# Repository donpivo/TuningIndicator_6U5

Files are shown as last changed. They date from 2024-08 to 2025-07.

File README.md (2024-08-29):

# TuningIndicator_6U5
Project description: https://retronics.no/2024/08/29/diy-digital-6u5-magic-eye-replacement/
All PCB design files (KiCAD), fabrication files (gerber), 3D models (.stl) and code (C++, PlatformIO) are shared for personal use only; not for commercial use / sale of neither the complete solution nor parts of it.

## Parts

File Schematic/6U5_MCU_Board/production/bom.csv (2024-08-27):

Designator | Footprint | Quantity | Value | LCSC Part #
C1, C10, C3, C8, C9 | 0603 | 5 | 100nF
C2, C4, C5 | 0603 | 3 | 10µF
C6, C7 | 0603 | 2 | 20pF
FB1 | 0603 | 1 | 1kΩ@100MHz 500mΩ@DC
J1 | PinHeader_1x03_P2.54mm_Horizontal_Alt | 1 | Pin header
J2 | EMI_Shield_MS207-10S | 1 | EMI Shield
J3 | 0527450897 | 1 | FFC8
J4 | 505110-1292 | 1 | Display interface
Q1 | SOT-23 | 1 | BC847C
R1, R4 | 0603 | 2 | 10kΩ
R2 | 0603 | 1 | 2.2MΩ
R3 | 0603 | 1 | 15MΩ
R5 | 0603 | 1 | 1MΩ
R6 | 0603 | 1 | 10Ω
R7 | 0603 | 1 | 1kΩ
U1 | SOT-23-5 | 1 | MCP6001T-I/OT
U2 | LQFP-48_7x7mm_P0.5mm | 1 | STM32F103CBTx
U3 | SOT-223-3_TabPin2 | 1 | NCP1117-3.3_SOT223
Y1 | Crystal_SMD_3225-4Pin_3.2x2.5mm | 1 | XC32M4-8.000 12pF

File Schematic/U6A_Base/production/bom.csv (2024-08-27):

Designator | Footprint | Quantity | Value | LCSC Part #
C1 | CP_Radial_D8.0mm_P3.50mm_H21mm | 1 | 1000µF 16V
D1, D2 | D_SOD-323_HandSoldering | 2 | 1N5819WS
F1 | 1206 | 1 | T1A
FB1 | 0805 | 1 | 330Ω@100MHz
J1 | U6A_Base | 1 | U6A Base
J2 | PinSocket_1x03_P2.54mm_Vertical | 1 | Pin header

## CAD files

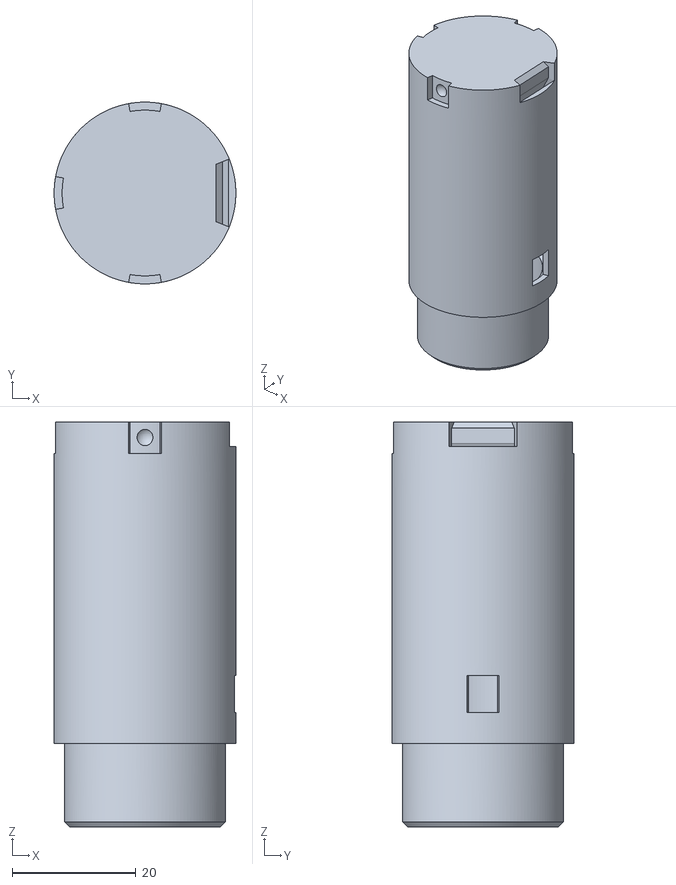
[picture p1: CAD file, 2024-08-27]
Models/6U5_Tube.stl
29.4 x 29.4 x 65.5

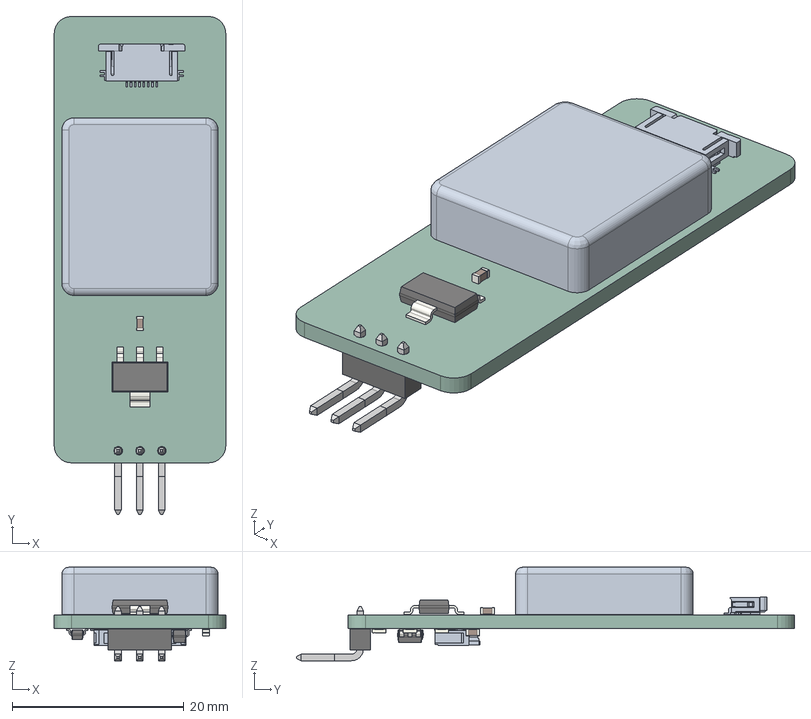
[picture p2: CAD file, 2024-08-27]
Schematic/6U5_MCU_Board/6U5_MCU_Board.step
20.0 x 58.0 x 10.9 mm
MS207-10S
SOT_223
C_0603_1608Metric x 3
R_0603_1608Metric x 3
SOT_23
SOT_23_5
PinHeader_022052031 v4
U6A_MCU_Board_PCB

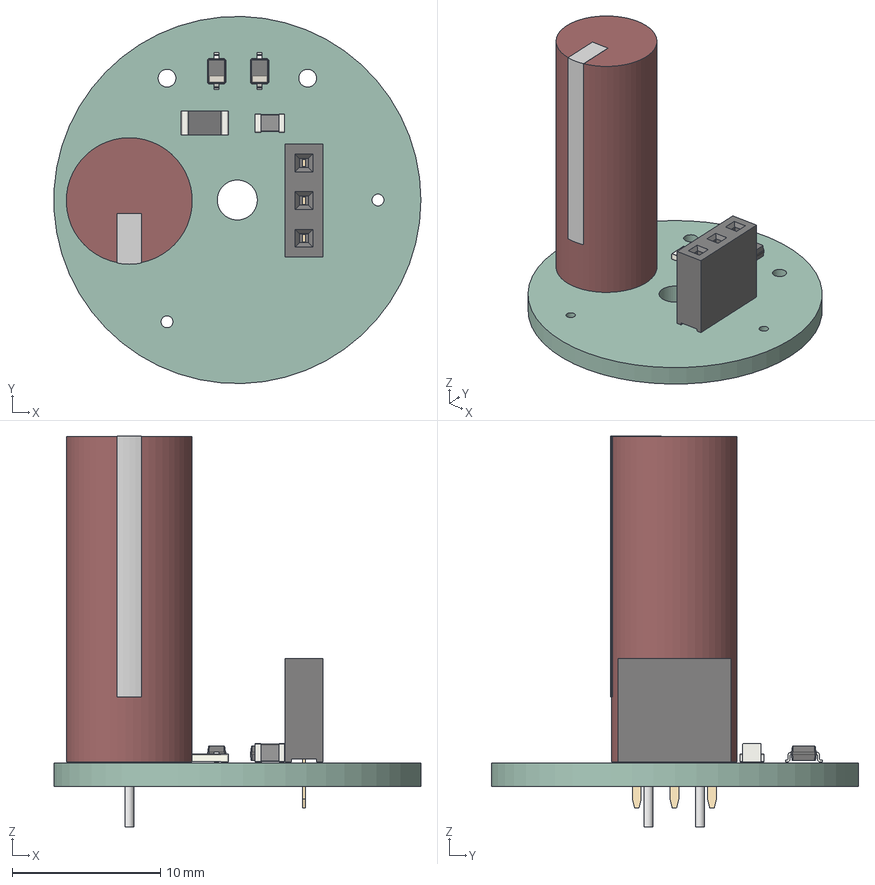
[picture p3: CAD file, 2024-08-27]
Schematic/U6A_Base/U6A_Base.step
24.8 x 24.8 x 26.4 mm
D_SOD_323 x 2
Fuse_1206_3216Metric
L_0805_2012Metric
PinSocket_1x03_P254mm_Vertical
U6A_Base_PCB

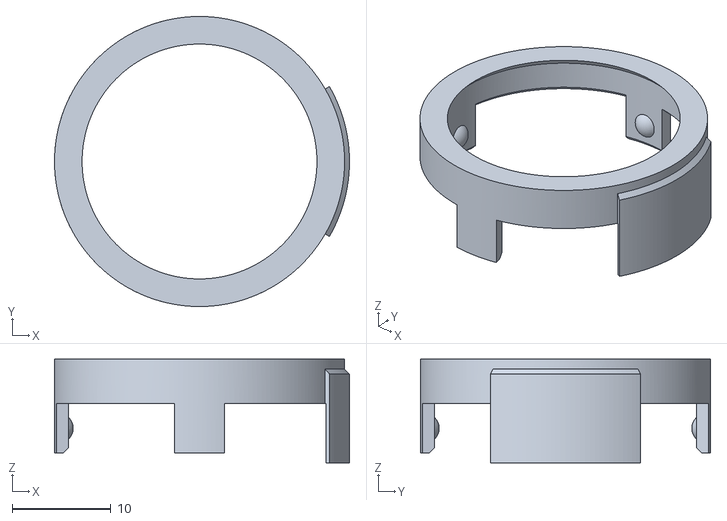
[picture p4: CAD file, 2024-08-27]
Models/6U5_DisplayBracket.stl
29.9 x 29.4 x 10.5

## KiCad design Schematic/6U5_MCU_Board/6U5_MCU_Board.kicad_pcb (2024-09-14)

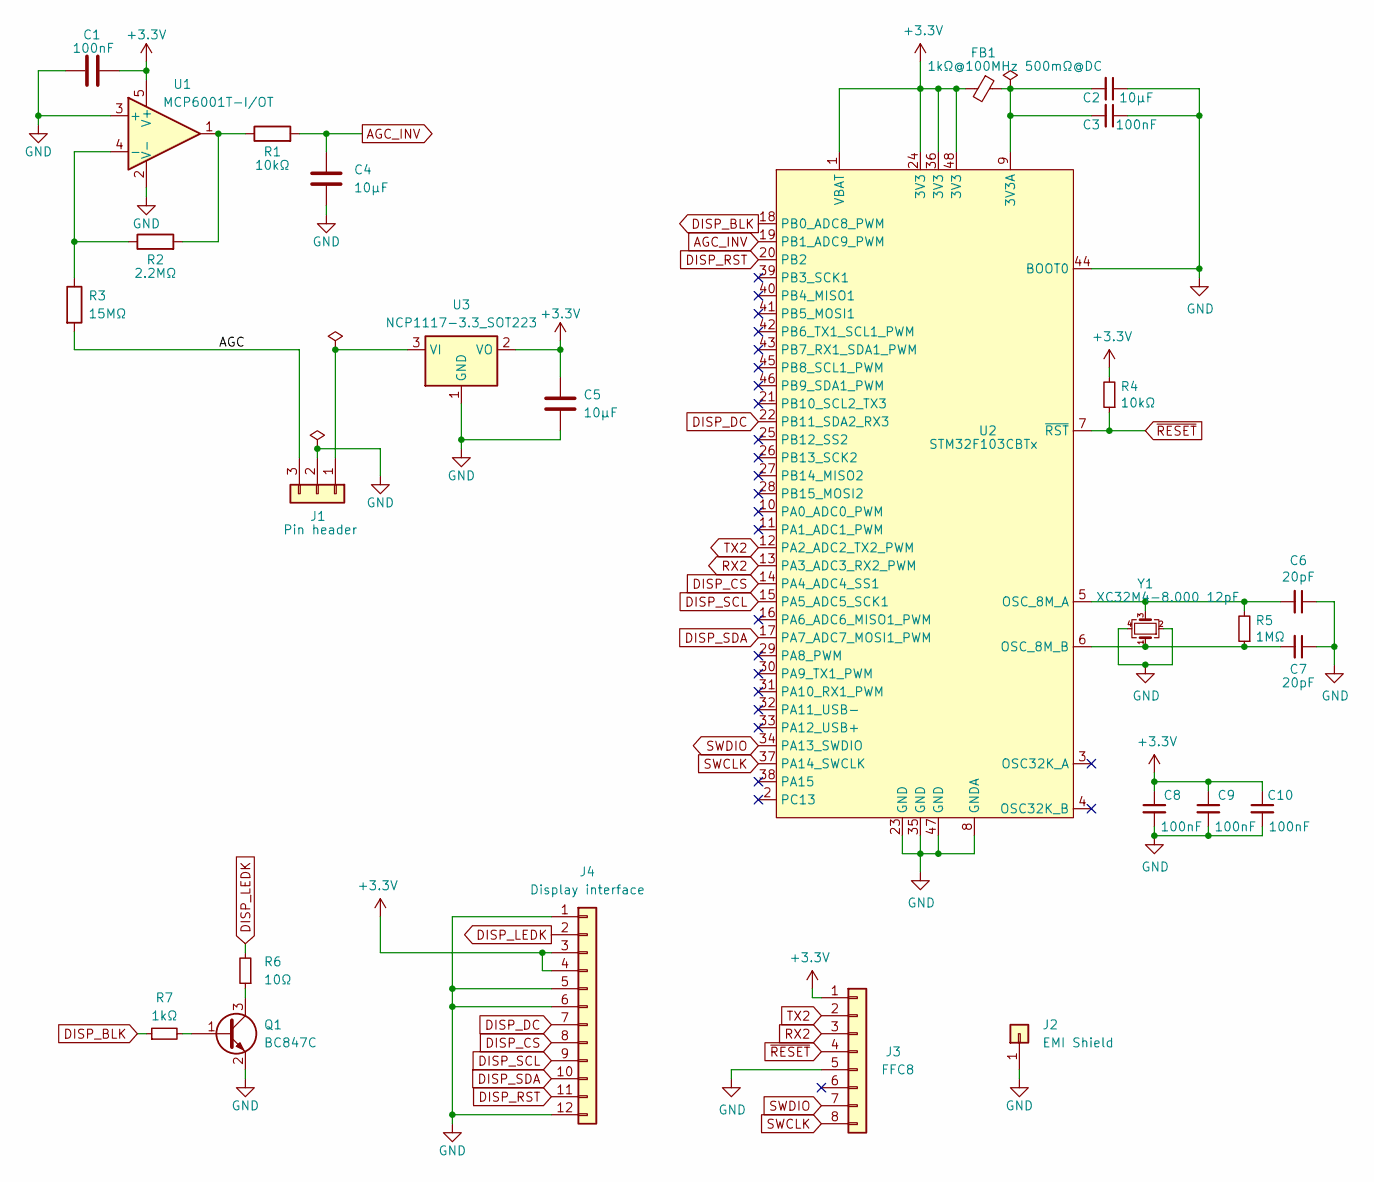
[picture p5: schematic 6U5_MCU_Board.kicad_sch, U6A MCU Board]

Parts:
C1, C3, C8, C9, C10: 100nF; C_0603_1608Metric_Pad1.08x0.95mm_HandSolder
C2, C4, C5: 10µF; C_0603_1608Metric_Pad1.08x0.95mm_HandSolder
C6, C7: 20pF; C_0603_1608Metric_Pad1.08x0.95mm_HandSolder
FB1: 1kΩ@100MHz 500mΩ@DC; L_0603_1608Metric_Pad1.05x0.95mm_HandSolder
J1: Pin header; PinHeader_1x03_P2.54mm_Horizontal_Alt
J2: EMI Shield; EMI_Shield_MS207-10S
J3: FFC8; 0527450897
J4: Display interface; 505110-1292
Q1: BC847C; SOT-23
R1, R4: 10kΩ; R_0603_1608Metric_Pad0.98x0.95mm_HandSolder
R2: 2.2MΩ; R_0603_1608Metric_Pad0.98x0.95mm_HandSolder
R3: 15MΩ; R_0603_1608Metric_Pad0.98x0.95mm_HandSolder
R5: 1MΩ; R_0603_1608Metric_Pad0.98x0.95mm_HandSolder
R6: 10Ω; R_0603_1608Metric_Pad0.98x0.95mm_HandSolder
R7: 1kΩ; R_0603_1608Metric_Pad0.98x0.95mm_HandSolder
U1: MCP6001T-I/OT; SOT-23-5
U2: STM32F103CBTx; LQFP-48_7x7mm_P0.5mm
U3: NCP1117-3.3_SOT223; SOT-223-3_TabPin2
Y1: XC32M4-8.000 12pF; Crystal_SMD_3225-4Pin_3.2x2.5mm

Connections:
+3.3V: C1.2, C5.1, C8.1, C9.1, C10.1, FB1.2, J3.1, J4.3, J4.4, R4.2, U1.5 (V+), U2.1 (VBAT), U2.24 (3V3), U2.36 (3V3), U2.48 (3V3), U3.2 (VO)
/AGC: J1.3, R3.2
AGC_INV: C4.1, R1.2, U2.19 (PB1_ADC9_PWM)
DISP_BLK: R7.1, U2.18 (PB0_ADC8_PWM)
DISP_CS: J4.8, U2.14 (PA4_ADC4_SS1)
DISP_DC: J4.7, U2.22 (PB11_SDA2_RX3)
DISP_LEDK: J4.2, R6.2
DISP_RST: J4.11, U2.20 (PB2)
DISP_SCL: J4.9, U2.15 (PA5_ADC5_SCK1)
DISP_SDA: J4.10, U2.17 (PA7_ADC7_MOSI1_PWM)
GND: C1.1, C2.1, C3.1, C4.2, C5.2, C6.1, C7.1, C8.2, C9.2, C10.2, J1.2, J2.1, J3.5, J4.1, J4.5, J4.6, J4.12, Q1.2 (E), U1.2 (V-), U1.3 (+), U2.8 (GNDA), U2.23 (GND), U2.35 (GND), U2.44 (BOOT0), U2.47 (GND), U3.1 (GND), Y1.2, Y1.4
unnamed: J1.1, U3.3 (VI)
unnamed: Q1.1 (B), R7.2
unnamed: Q1.3 (C), R6.1
unnamed: R1.1, R2.2, U1.1
unnamed: R2.1, R3.1, U1.4 (-)
unnamed: C2.2, C3.2, FB1.1, U2.9 (3V3A)
unnamed: C6.2, R5.2, U2.5 (OSC_8M_A), Y1.3
unnamed: C7.2, R5.1, U2.6 (OSC_8M_B), Y1.1
RX2: J3.3, U2.13 (PA3_ADC3_RX2_PWM)
SWCLK: J3.8, U2.37 (PA14_SWCLK)
SWDIO: J3.7, U2.34 (PA13_SWDIO)
TX2: J3.2, U2.12 (PA2_ADC2_TX2_PWM)
~RESET: J3.4, R4.1, U2.7 (~RST)

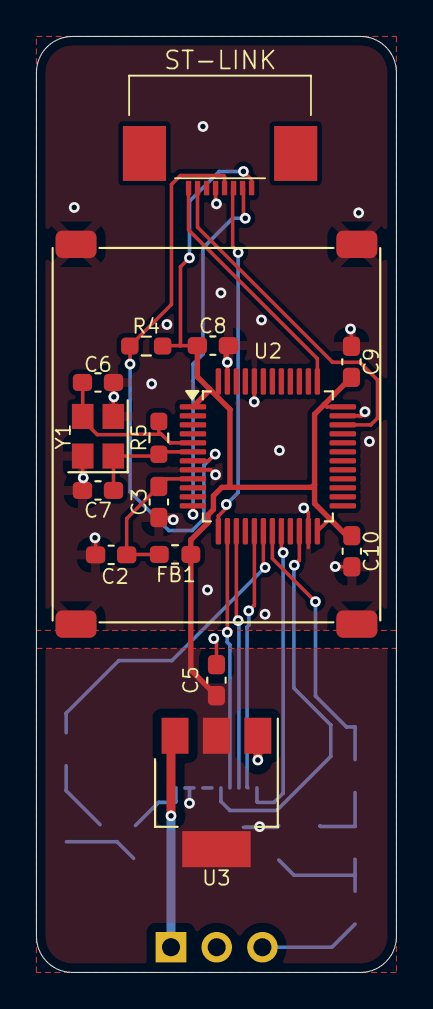
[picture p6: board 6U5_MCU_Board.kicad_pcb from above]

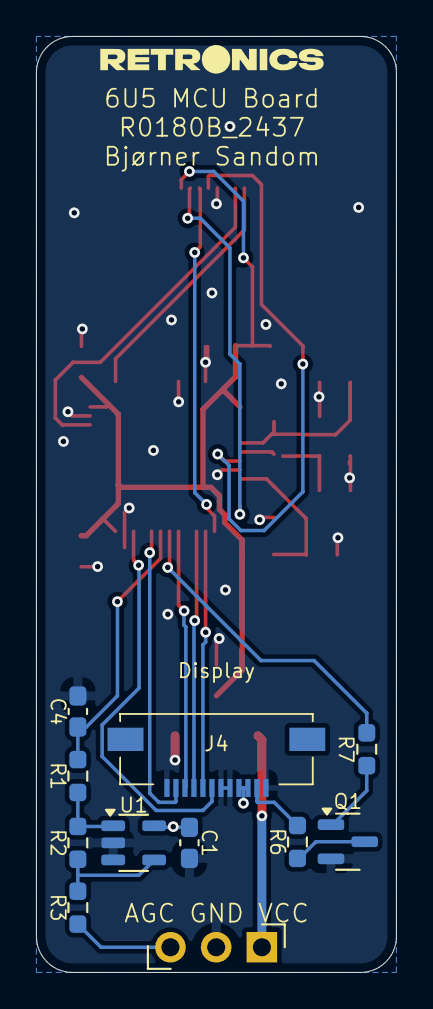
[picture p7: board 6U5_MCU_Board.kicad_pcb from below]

Board: 2 copper layers, 20.0 x 52.0 mm, 27 parts (11 on the bottom side), 24 nets.

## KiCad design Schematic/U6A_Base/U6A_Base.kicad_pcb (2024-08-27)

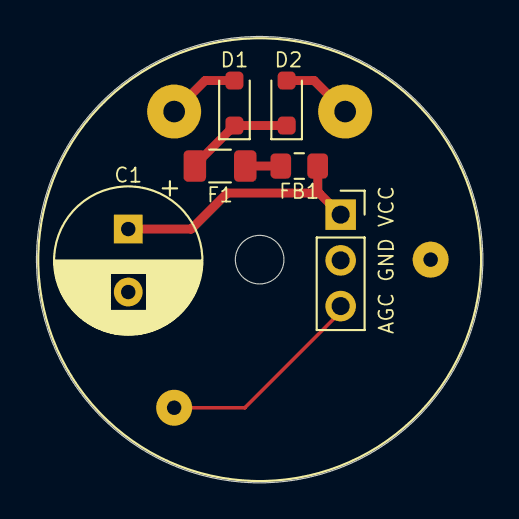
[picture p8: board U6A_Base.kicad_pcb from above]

Board: 2 copper layers, 24.8 x 24.8 mm, 8 parts (0 on the bottom side), 7 nets.

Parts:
C1: 1000µF 16V; CP_Radial_D8.0mm_P3.50mm_H21mm
D1, D2: 1N5819WS; D_SOD-323_HandSoldering
F1: T1A; Fuse_1206_3216Metric
FB1: 330Ω@100MHz; L_0805_2012Metric_Pad1.15x1.40mm_HandSolder
H1: MountingHole; MountingHole_2.7mm_M2.5
J1: U6A Base; U6A_Base
J2: Pin header; PinSocket_1x03_P2.54mm_Vertical

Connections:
AGC: J1.3, J2.3
GND: C1.2, J1.5, J2.2
H1: D1.2 (A), J1.1
H2: D2.2 (A), J1.6
unnamed: D1.1 (K), D2.1 (K), F1.1
unnamed: F1.2, FB1.1
VCC: C1.1, FB1.2, J2.1

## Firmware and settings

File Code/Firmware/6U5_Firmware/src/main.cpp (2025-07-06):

/*
6U5 Digital Replica by retronics.no
*/

#include <Arduino.h> 
#include <Arduino_GFX_Library.h> //https://github.com/moononournation/Arduino_GFX | GFX Library for Arduino@^1.4.7

#define PIN_BACKLIGHT PB0
#define PIN_DC PB11 
#define PIN_CS PA4  
#define PIN_RES PB2
// PIN_SCL A5
// PIN_SDA A7
#define GREEN_BRIGHT RGB565(0, 255, 80)
#define GREEN_MEDIUM RGB565(0, 180, 60)
#define GREEN_DARK RGB565(0, 80, 35)
#define CENTER_X 63
#define CENTER_Y 75
#define OUTER_RADIUS 52
#define INNER_RADIUS 24
#define PIN_AGC PB1
#define BRIGHTNESS 255 // Max 255

Arduino_DataBus *bus = new Arduino_HWSPI(PIN_DC, PIN_CS);
Arduino_GFX *gfx = new Arduino_GC9107(bus, PIN_RES, 0 /* rotation */, true /* IPS */, GC9107_TFTWIDTH, GC9107_TFTHEIGHT, 0, 0, 0, 0);
HardwareSerial uart2(PA3, PA2);
uint8_t oldHalfAngle;
uint32_t lastDisplayUpdate=millis();
double agcFiltered;
uint32_t lastDirectionChange=millis();
uint8_t fadeInCounter=0;
uint32_t fadeInLastChange=millis();

void drawLine(uint16_t angle, uint16_t lineColor);

void setup(void)
{
  analogWriteResolution(16);
  uart2.begin(115200);
  pinMode(PIN_AGC, INPUT);
  pinMode(PIN_BACKLIGHT, OUTPUT);
  digitalWrite(PIN_BACKLIGHT,LOW);
  uart2.println("Digital 6U5 replacement.");

  //Display startup
  if (!gfx->begin())
  {
    uart2.println("gfx->begin() failed!");
  }
  gfx->fillScreen(BLACK);
  for(int16_t i = 46; i < 315; i++)
  {
    drawLine(i,GREEN_MEDIUM);
  }
  drawLine(315, GREEN_BRIGHT);
  drawLine(45, GREEN_BRIGHT);
  for(int16_t i = 316; i < 404; i++)
  {
    drawLine(i,GREEN_DARK);
  }
  delay(1000);
}

void loop()
{
  //Fade in
  if((fadeInCounter<BRIGHTNESS)&&(millis()-fadeInLastChange)>(120-(fadeInCounter/4)))
  {
    fadeInCounter++;
    analogWrite(PIN_BACKLIGHT, fadeInCounter*fadeInCounter);
    fadeInLastChange=millis();
  }
  //AGC measurement, filtering and mapping to display angle
  uint16_t agcRaw=analogRead(PIN_AGC);
  agcFiltered=(9.0*agcFiltered+agcRaw)/10.0;
  uint8_t newHalfAngle=(uint8_t)(((agcFiltered/11)+15.0*log10(1+agcFiltered))/3);
  newHalfAngle=newHalfAngle>45?45:newHalfAngle;

  //Display update
  if(newHalfAngle>oldHalfAngle)
  {
    for(int8_t i=oldHalfAngle; i<newHalfAngle; i++)
    {
      drawLine(315+i,GREEN_MEDIUM);
      drawLine(405-i,GREEN_MEDIUM);
    }
    drawLine(315+newHalfAngle,GREEN_BRIGHT);
    drawLine(405-newHalfAngle,GREEN_BRIGHT);
  }
  else if(newHalfAngle<oldHalfAngle)
  {
    for(int8_t i=oldHalfAngle; i>newHalfAngle; i--)
    {
      drawLine(315+i,GREEN_DARK);
      drawLine(405-i,GREEN_DARK);
    }
    drawLine(315+newHalfAngle,GREEN_BRIGHT);
    drawLine(405-newHalfAngle,GREEN_BRIGHT);
  }
  oldHalfAngle=newHalfAngle;
}


void drawLine(uint16_t angle, uint16_t lineColor)
{
  double sinVal = sin(angle*0.0174533);
  double cosVal = cos(angle*0.0174533);
  gfx->drawLine(CENTER_X+sinVal*INNER_RADIUS, CENTER_Y+cosVal*INNER_RADIUS, CENTER_X+sinVal*OUTER_RADIUS, CENTER_Y+cosVal*OUTER_RADIUS, lineColor);
  gfx->drawLine(CENTER_X+sinVal*INNER_RADIUS, CENTER_Y+1+cosVal*INNER_RADIUS, CENTER_X+sinVal*OUTER_RADIUS, CENTER_Y+1+cosVal*OUTER_RADIUS, lineColor);
}

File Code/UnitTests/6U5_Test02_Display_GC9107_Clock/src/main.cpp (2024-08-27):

#include <Arduino.h>
#include <Arduino_GFX_Library.h>

#define PIN_BACKLIGHT PB0
#define PIN_DC PA1
#define PIN_CS PA4
#define PIN_RES A0
// PIN_SCL A5
// PIN_SDA A7

#define BACKGROUND BLACK
#define MARK_COLOR WHITE
#define SUBMARK_COLOR DARKGREY // LIGHTGREY
#define HOUR_COLOR WHITE
#define MINUTE_COLOR BLUE // LIGHTGREY
#define SECOND_COLOR RED

#define SIXTIETH 0.016666667
#define TWELFTH 0.08333333
#define SIXTIETH_RADIAN 0.10471976
#define TWELFTH_RADIAN 0.52359878
#define RIGHT_ANGLE_RADIAN 1.5707963

Arduino_DataBus *bus = new Arduino_HWSPI(PIN_DC, PIN_CS);
Arduino_GFX *gfx = new Arduino_GC9107(bus, PIN_RES, 0 /* rotation */, true /* IPS */);

HardwareSerial uart2(PA3, PA2);

static uint8_t conv2d(const char *p)
{
  uint8_t v = 0;
  return (10 * (*p - '0')) + (*++p - '0');
}

static int16_t w, h, center;
static int16_t hHandLen, mHandLen, sHandLen, markLen;
static float sdeg, mdeg, hdeg;
static int16_t osx = 0, osy = 0, omx = 0, omy = 0, ohx = 0, ohy = 0; // Saved H, M, S x & y coords
static int16_t nsx, nsy, nmx, nmy, nhx, nhy;                         // H, M, S x & y coords
static int16_t xMin, yMin, xMax, yMax;                               // redraw range
static int16_t hh, mm, ss;
static unsigned long targetTime; // next action time

static int16_t *cached_points;
static uint16_t cached_points_idx = 0;
static int16_t *last_cached_point;
void draw_round_clock_mark(int16_t innerR1, int16_t outerR1, int16_t innerR2, int16_t outerR2, int16_t innerR3, int16_t outerR3);
void draw_square_clock_mark(int16_t innerR1, int16_t outerR1, int16_t innerR2, int16_t outerR2, int16_t innerR3, int16_t outerR3);
void redraw_hands_cached_draw_and_erase();
void draw_and_erase_cached_line(int16_t x0, int16_t y0, int16_t x1, int16_t y1, int16_t color, int16_t *cache, int16_t cache_len, bool cross_check_second, bool cross_check_hour);
void write_cache_pixel(int16_t x, int16_t y, int16_t color, bool cross_check_second, bool cross_check_hour);

void setup(void)
{
  uart2.begin(115200);
  uart2.println("Arduino_GFX Clock example GC9107");
  pinMode(PIN_BACKLIGHT, OUTPUT);
  digitalWrite(PIN_BACKLIGHT,HIGH);
  // Init Display
  if (!gfx->begin())
  {
    uart2.println("gfx->begin() failed!");
  }
  gfx->fillScreen(BACKGROUND);
  // init LCD constant
  w = gfx->width();
  h = gfx->height();
  if (w < h)
  {
    center = w / 2;
  }
  else
  {
    center = h / 2;
  }
  hHandLen = center * 3 / 8;
  mHandLen = center * 2 / 3;
  sHandLen = center * 5 / 6;
  markLen = sHandLen / 6;
  cached_points = (int16_t *)malloc((hHandLen + 1 + mHandLen + 1 + sHandLen + 1) * 2 * 2);

  // Draw 60 clock marks
  draw_round_clock_mark(
      // draw_square_clock_mark(
      center - markLen, center,
      center - (markLen * 2 / 3), center,
      center - (markLen / 2), center);

  hh = conv2d(__TIME__);
  mm = conv2d(__TIME__ + 3);
  ss = conv2d(__TIME__ + 6);

  targetTime = ((millis() / 1000) + 1) * 1000;

  
}

void loop()
{
  unsigned long cur_millis = millis();
  if (cur_millis >= targetTime)
  {
    targetTime += 1000;
    ss++; // Advance second
    if (ss == 60)
    {
      ss = 0;
      mm++; // Advance minute
      if (mm > 59)
      {
        mm = 0;
        hh++; // Advance hour
        if (hh > 23)
        {
          hh = 0;
        }
      }
    }
  }

  // Pre-compute hand degrees, x & y coords for a fast screen update
  sdeg = SIXTIETH_RADIAN * ((0.001 * (cur_millis % 1000)) + ss); // 0-59 (includes millis)
  nsx = cos(sdeg - RIGHT_ANGLE_RADIAN) * sHandLen + center;
  nsy = sin(sdeg - RIGHT_ANGLE_RADIAN) * sHandLen + center;
  if ((nsx != osx) || (nsy != osy))
  {
    mdeg = (SIXTIETH * sdeg) + (SIXTIETH_RADIAN * mm); // 0-59 (includes seconds)
    hdeg = (TWELFTH * mdeg) + (TWELFTH_RADIAN * hh);   // 0-11 (includes minutes)
    mdeg -= RIGHT_ANGLE_RADIAN;
    hdeg -= RIGHT_ANGLE_RADIAN;
    nmx = cos(mdeg) * mHandLen + center;
    nmy = sin(mdeg) * mHandLen + center;
    nhx = cos(hdeg) * hHandLen + center;
    nhy = sin(hdeg) * hHandLen + center;

    // redraw hands
    redraw_hands_cached_draw_and_erase();

    ohx = nhx;
    ohy = nhy;
    omx = nmx;
    omy = nmy;
    osx = nsx;
    osy = nsy;

    delay(1);
  }
}


void draw_round_clock_mark(int16_t innerR1, int16_t outerR1, int16_t innerR2, int16_t outerR2, int16_t innerR3, int16_t outerR3)
{
  float x, y;
  int16_t x0, x1, y0, y1, innerR, outerR;
  uint16_t c;

  for (uint8_t i = 0; i < 60; i++)
  {
    if ((i % 15) == 0)
    {
      innerR = innerR1;
      outerR = outerR1;
      c = MARK_COLOR;
    }
    else if ((i % 5) == 0)
    {
      innerR = innerR2;
      outerR = outerR2;
      c = MARK_COLOR;
    }
    else
    {
      innerR = innerR3;
      outerR = outerR3;
      c = SUBMARK_COLOR;
    }

    mdeg = (SIXTIETH_RADIAN * i) - RIGHT_ANGLE_RADIAN;
    x = cos(mdeg);
    y = sin(mdeg);
    x0 = x * outerR + center;
    y0 = y * outerR + center;
    x1 = x * innerR + center;
    y1 = y * innerR + center;

    gfx->drawLine(x0, y0, x1, y1, c);
  }
}

void draw_square_clock_mark(int16_t innerR1, int16_t outerR1, int16_t innerR2, int16_t outerR2, int16_t innerR3, int16_t outerR3)
{
  float x, y;
  int16_t x0, x1, y0, y1, innerR, outerR;
  uint16_t c;

  for (uint8_t i = 0; i < 60; i++)
  {
    if ((i % 15) == 0)
    {
      innerR = innerR1;
      outerR = outerR1;
      c = MARK_COLOR;
    }
    else if ((i % 5) == 0)
    {
      innerR = innerR2;
      outerR = outerR2;
      c = MARK_COLOR;
    }
    else
    {
      innerR = innerR3;
      outerR = outerR3;
      c = SUBMARK_COLOR;
    }

    if ((i >= 53) || (i < 8))
    {
      x = tan(SIXTIETH_RADIAN * i);
      x0 = center + (x * outerR);
      y0 = center + (1 - outerR);
      x1 = center + (x * innerR);
      y1 = center + (1 - innerR);
    }
    else if (i < 23)
    {
      y = tan((SIXTIETH_RADIAN * i) - RIGHT_ANGLE_RADIAN);
      x0 = center + (outerR);
      y0 = center + (y * outerR);
      x1 = center + (innerR);
      y1 = center + (y * innerR);
    }
    else if (i < 38)
    {
      x = tan(SIXTIETH_RADIAN * i);
      x0 = center - (x * outerR);
      y0 = center + (outerR);
      x1 = center - (x * innerR);
      y1 = center + (innerR);
    }
    else if (i < 53)
    {
      y = tan((SIXTIETH_RADIAN * i) - RIGHT_ANGLE_RADIAN);
      x0 = center + (1 - outerR);
      y0 = center - (y * outerR);
      x1 = center + (1 - innerR);
      y1 = center - (y * innerR);
    }
    gfx->drawLine(x0, y0, x1, y1, c);
  }
}

void redraw_hands_cached_draw_and_erase()
{
  gfx->startWrite();
  draw_and_erase_cached_line(center, center, nsx, nsy, SECOND_COLOR, cached_points, sHandLen + 1, false, false);
  draw_and_erase_cached_line(center, center, nhx, nhy, HOUR_COLOR, cached_points + ((sHandLen + 1) * 2), hHandLen + 1, true, false);
  draw_and_erase_cached_line(center, center, nmx, nmy, MINUTE_COLOR, cached_points + ((sHandLen + 1 + hHandLen + 1) * 2), mHandLen + 1, true, true);
  gfx->endWrite();
}
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

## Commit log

2024-08-29 Brightness and color adjustment
    [6U5_MCU_Board.kicad_pcb]
2024-08-29 Added display driver library reference
2024-08-31 Removed unused code
    [6U5_MCU_Board.kicad_sch]
2024-09-03 Re-attached EMI shield
    [6U5_MCU_Board.kicad_pcb]
2024-09-14 Added thermal reliefs on bottom ground plane
    [6U5_MCU_Board.kicad_pcb]
